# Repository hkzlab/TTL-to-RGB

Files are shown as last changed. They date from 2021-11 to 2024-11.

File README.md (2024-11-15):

# MDA/CGA/EGA/HERCULES TTL-to-ANALOG Converter

## Introduction

This board converts CGA/EGA/MDA/Hercules TTL signals into analog RGB signals that can be fed into a compatible monitor.

Depending on jumper settings, it can automatically detect MDA/Hercules and Hi-res EGA modes (uses vsync polarity detection), can be forced into low-res 64 colors EGA and can perform the "brown-fix" for CGA.

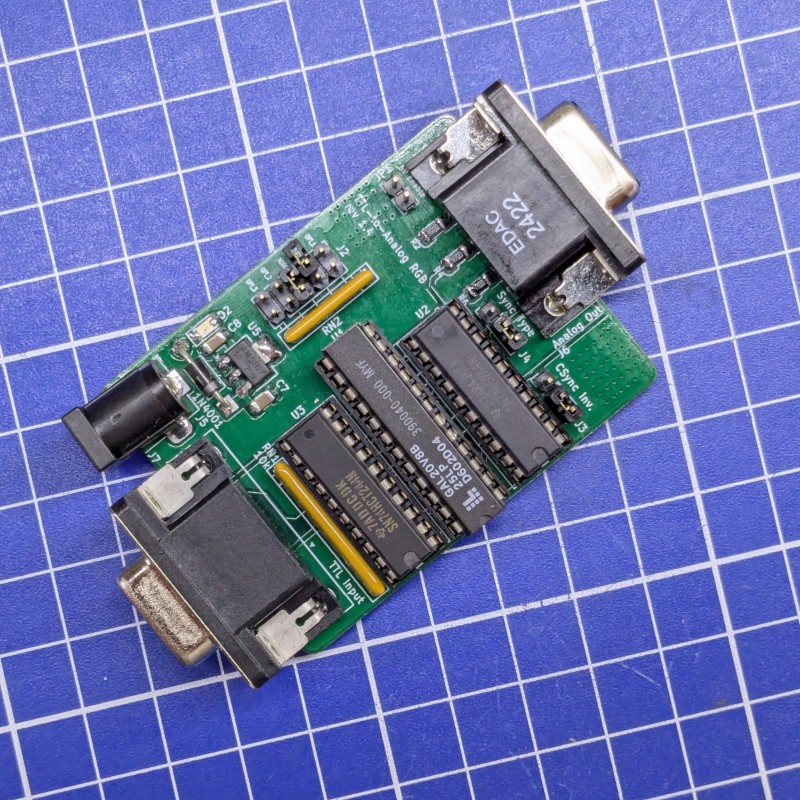
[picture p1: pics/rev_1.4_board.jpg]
Rev. 1.4 Board


The board uses a GAL20V8 PLD to implement the conversions, sync polarity detection, brown-fix, etc.

The PLD is sandwiched between two '244 buffers to protect it from shorts and allow the user to experiment with different logic families to better handle the input. It is recommended to use an 'LS244 as the output buffer, an LS or an HCT is fine for the input.

This board does NOT perform any frequency conversion. You will need a monitor capable of syncing to 15, 18 and 21Khz.

### Pics!

Example of an hi-res EGA game
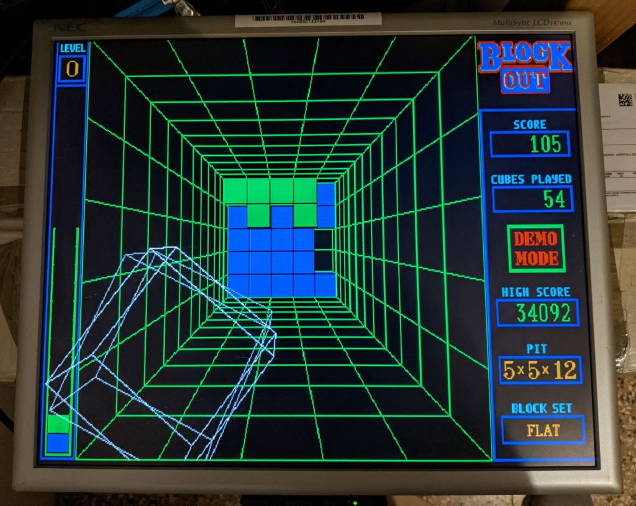
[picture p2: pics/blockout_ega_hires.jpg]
Block Out


Example of a low-res EGA game, with palette choosen between the 64 EGA colors (instead of the 16 CGA colors)
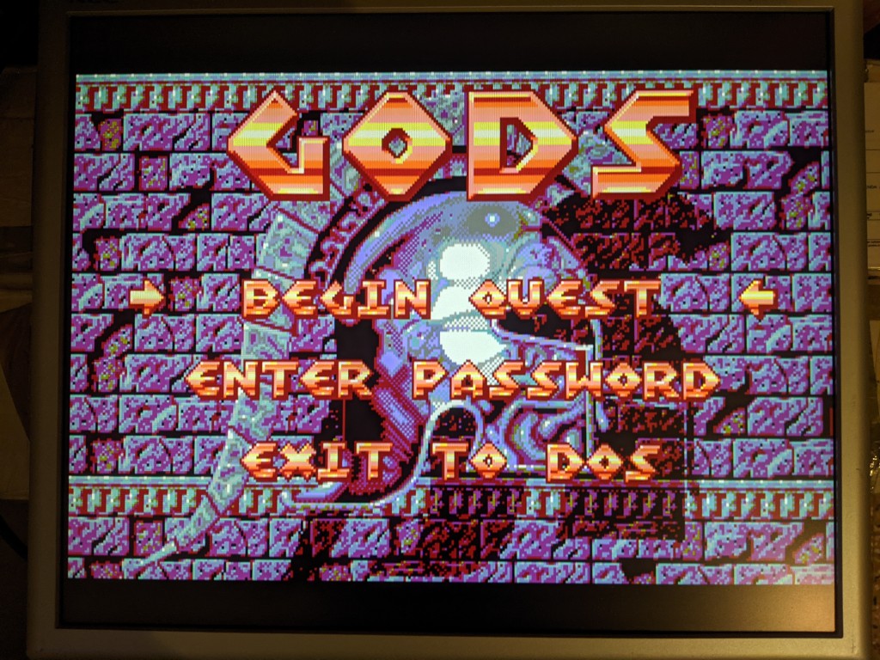
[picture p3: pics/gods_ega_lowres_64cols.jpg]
GODS


### Disclaimer

I take NO responsibility for what happens if you decide to build and use this card. Your computer might crash, catch fire or be destroyed in other nasty ways.
You're encourauged to take what you deem fit from this, and use it in your projects!

### Functionalities

✅ means I tested the functionality and it works, ❌ means I tested the functionality and found issues, ? means that the functionality has yet to be tested.

* [✅] CGA
* [✅] EGA, low-res
* [✅] EGA, low-res, 64 colors
* [✅] EGA, hi-res
* [✅] MDA
* [?] Hercules

## Bill of Materials

**TODO**

## Known Issues

### Rev 1.4

While this revision of the board is basically the same circuit of the previous revisions with some reorganization, the board has not been tested yet!

### Rev 1.2

* Optional power is connected to pin 15 of the HD15 connector, which is not ideal, as the best option would be pin 9. This will be fixed in a later revision (1.4)

### Rev 1.1

* Pin 13 of the GAL is tied to GND, and is currently used to switch between detection modes (CGA/MDA/HERCULES vs CGA/EGA). It can be fixed by a mod
* The board does not provide an option for power output on the HD15 connector. This can be fixed by a mod. Note that the mod will connect power to pin 15, which is not ideal (best would be pin 9), but connecting to the proper location requires desoldering the HD15 and cut more traces.
* With a 12v PSU the regulator gets hot. Use a PSU between 7 and 9v.

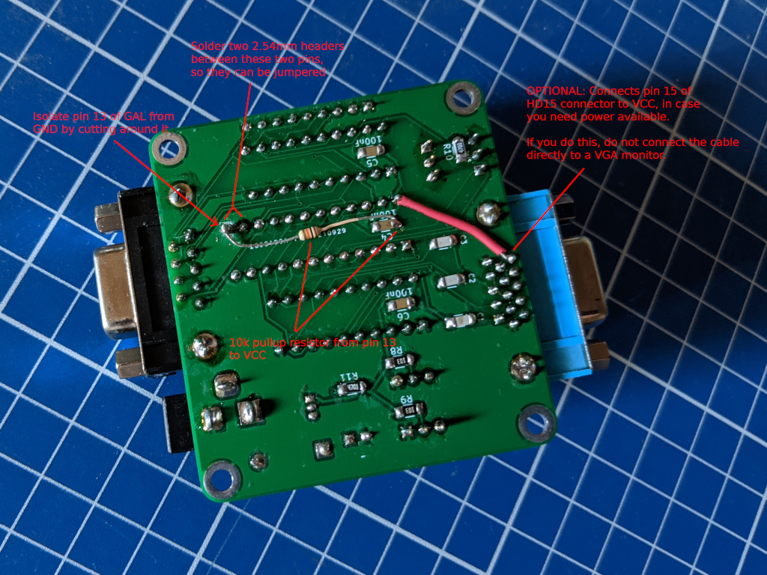
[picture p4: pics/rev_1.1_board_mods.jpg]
Rev. 1.1 Board Mods


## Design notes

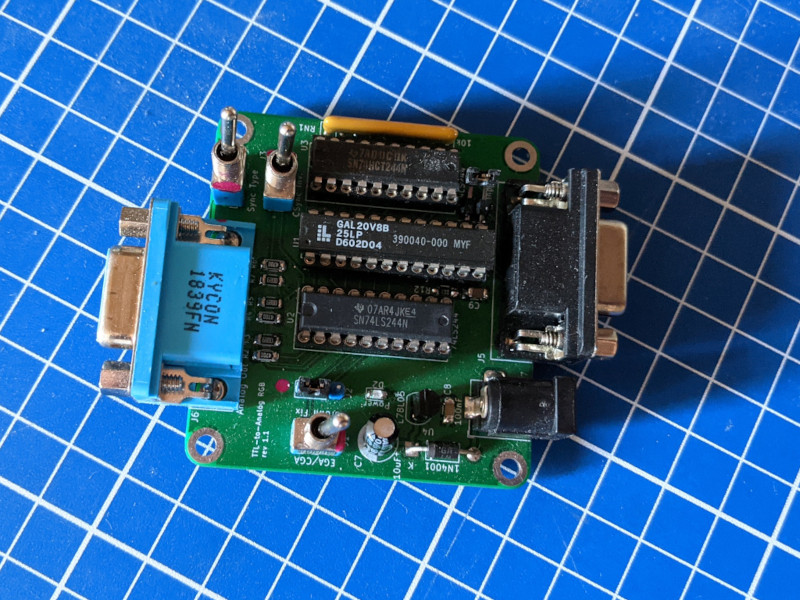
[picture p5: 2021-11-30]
pics/rev_1.1_board.jpg

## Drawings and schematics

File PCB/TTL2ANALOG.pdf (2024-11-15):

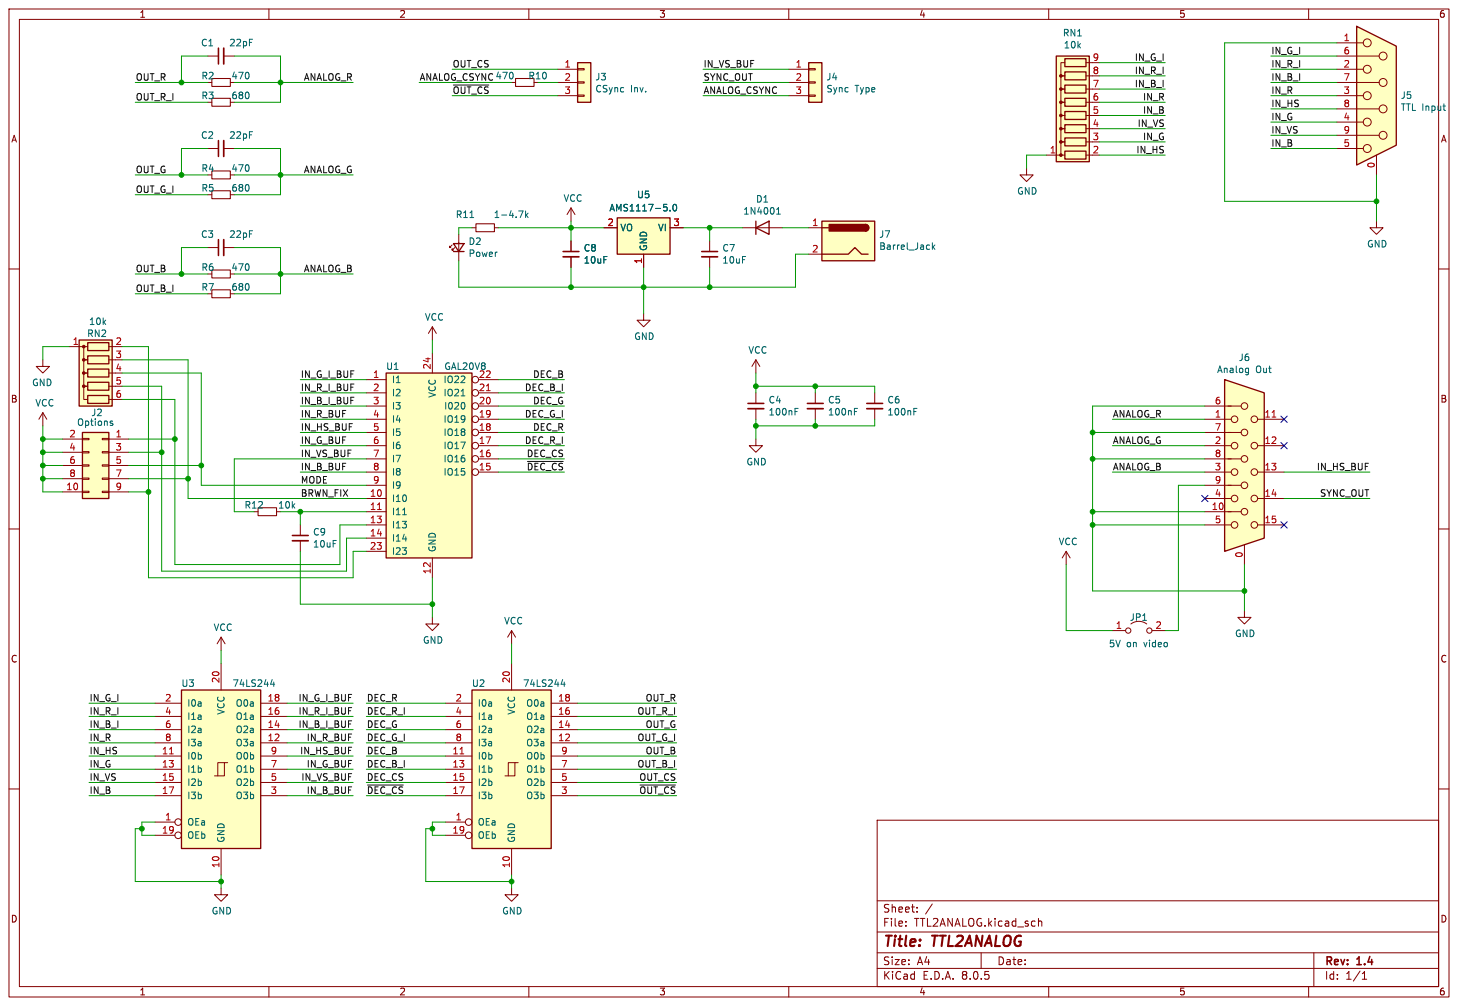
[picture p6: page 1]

1 VO 2 VI 3 U5 AMS1117-5.0 GND GND OEa 1 GND 10

File: TTL2ANALOG.kicad_sch Sheet: / GND 12 VCC 24

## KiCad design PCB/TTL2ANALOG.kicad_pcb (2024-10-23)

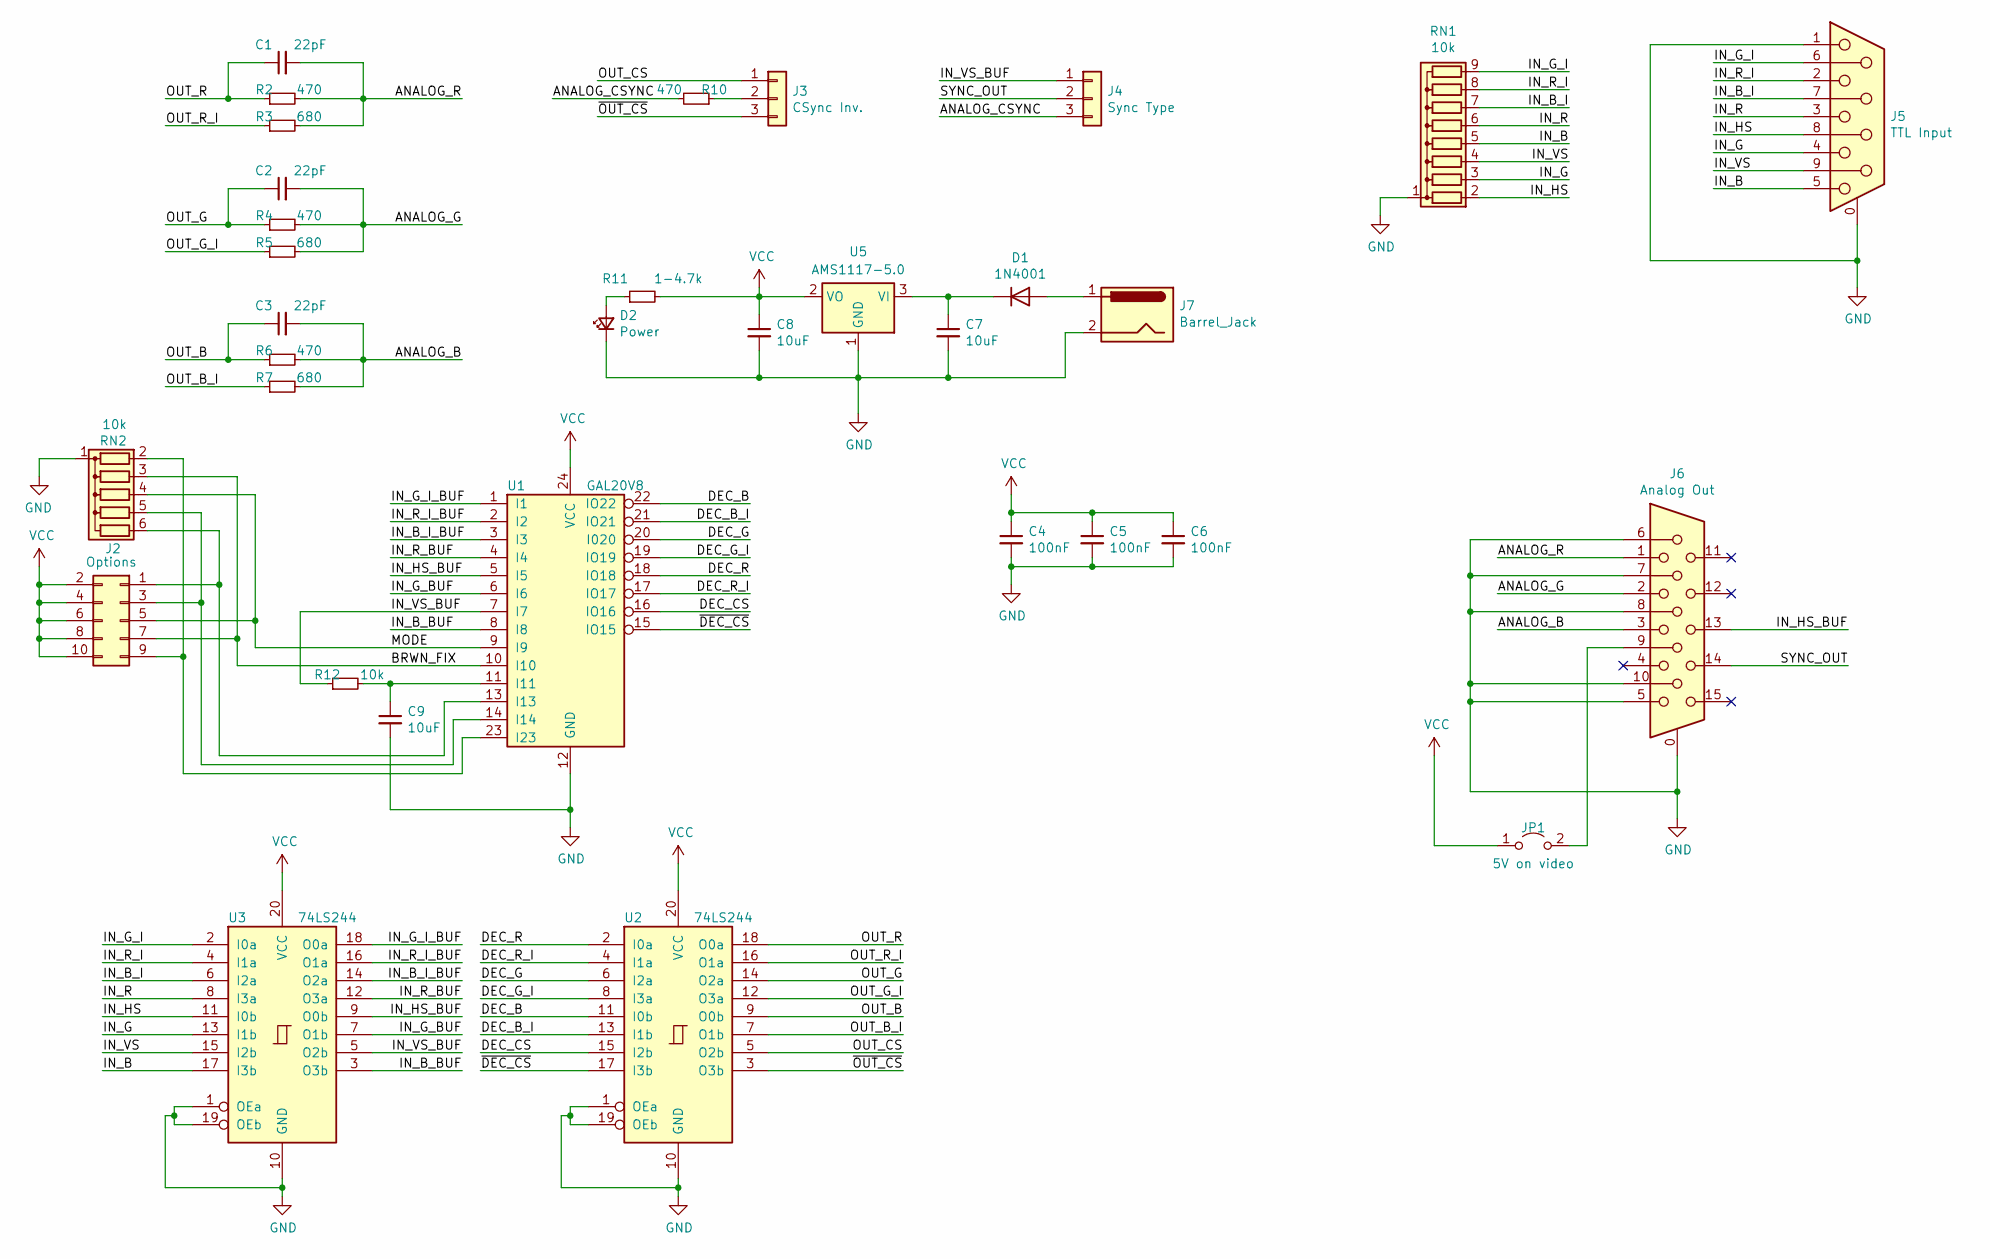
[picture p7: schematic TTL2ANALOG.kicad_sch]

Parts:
C1, C2, C3: 22pF; C_1206_3216Metric_Pad1.33x1.80mm_HandSolder
C4, C5, C6: 100nF; C_1206_3216Metric_Pad1.33x1.80mm_HandSolder
C7, C8, C9: 10uF; C_1206_3216Metric_Pad1.33x1.80mm_HandSolder
D1: 1N4001; D_DO-41_SOD81_P10.16mm_Horizontal
D2: Power; LED_1206_3216Metric_Pad1.42x1.75mm_HandSolder
J2: Options; PinHeader_2x05_P2.54mm_Vertical
J3: CSync Inv.; PinHeader_1x03_P2.54mm_Vertical
J4: Sync Type; PinHeader_1x03_P2.54mm_Vertical
J5: TTL Input; DSUB-9_Female_Horizontal_P2.77x2.84mm_EdgePinOffset4.94mm_H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
J6: Analog Out; DSUB-15-HD_Female_Horizontal_P2.29x1.98mm_EdgePinOffset3.03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
J7: Barrel_Jack; BarrelJack_Horizontal
JP1: 5V on video; PinHeader_1x02_P2.54mm_Vertical
R2, R4, R6, R10: 470; R_1206_3216Metric_Pad1.30x1.75mm_HandSolder
R3, R5, R7: 680; R_1206_3216Metric_Pad1.30x1.75mm_HandSolder
R11: 1-4.7k; R_1206_3216Metric_Pad1.30x1.75mm_HandSolder
R12: 10k; R_1206_3216Metric_Pad1.30x1.75mm_HandSolder
RN1: 10k; R_Array_SIP9
RN2: 10k; R_Array_SIP6
U1: GAL20V8; DIP-24_W7.62mm
U2, U3: 74LS244; DIP-20_W7.62mm_Socket
U5: AMS1117-5.0; SOT-223-3_TabPin2

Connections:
/ANALOG_B: C3.2, J6.3, R6.2, R7.2
/ANALOG_CSYNC: J4.3, R10.2
/ANALOG_G: C2.2, J6.2, R4.2, R5.2
/ANALOG_R: C1.2, J6.1, R2.2, R3.2
/BRWN_FIX: J2.7, RN2.3 (R2), U1.10 (I10)
/DEC_B: U1.22 (IO22), U2.11 (I0b)
/DEC_B_I: U1.21 (IO21), U2.13 (I1b)
/DEC_CS: U1.16 (IO16), U2.15 (I2b)
/DEC_G: U1.20 (I020), U2.6 (I2a)
/DEC_G_I: U1.19 (IO19), U2.8 (I3a)
/DEC_R: U1.18 (IO18), U2.2 (I0a)
/DEC_R_I: U1.17 (IO17), U2.4 (I1a)
/IN_B: J5.5, RN1.5 (R4), U3.17 (I3b)
/IN_B_BUF: U1.8 (I8), U3.3 (O3b)
/IN_B_I: J5.7, RN1.7 (R6), U3.6 (I2a)
/IN_B_I_BUF: U1.3 (I3), U3.14 (O2a)
/IN_G: J5.4, RN1.3 (R2), U3.13 (I1b)
/IN_G_BUF: U1.6 (I6), U3.7 (O1b)
/IN_G_I: J5.6, RN1.9 (R8), U3.2 (I0a)
/IN_G_I_BUF: U1.1 (I1), U3.18 (O0a)
/IN_HS: J5.8, RN1.2 (R1), U3.11 (I0b)
/IN_HS_BUF: J6.13, U1.5 (I5), U3.9 (O0b)
/IN_R: J5.3, RN1.6 (R5), U3.8 (I3a)
/IN_R_BUF: U1.4 (I4), U3.12 (O3a)
/IN_R_I: J5.2, RN1.8 (R7), U3.4 (I1a)
/IN_R_I_BUF: U1.2 (I2), U3.16 (O1a)
/IN_VS: J5.9, RN1.4 (R3), U3.15 (I2b)
/IN_VS_BUF: J4.1, R12.1, U1.7 (I7), U3.5 (O2b)
/MODE: J2.5, RN2.4 (R3), U1.9 (I9)
/OUT_B: C3.1, R6.1, U2.9 (O0b)
/OUT_B_I: R7.1, U2.7 (O1b)
/OUT_CS: J3.1, U2.5 (O2b)
/OUT_G: C2.1, R4.1, U2.14 (O2a)
/OUT_G_I: R5.1, U2.12 (O3a)
/OUT_R: C1.1, R2.1, U2.18 (O0a)
/OUT_R_I: R3.1, U2.16 (O1a)
/SYNC_OUT: J4.2, J6.14
/~DEC_CS: U1.15 (IO15), U2.17 (I3b)
/~OUT_CS: J3.3, U2.3 (O3b)
GND: C4.2, C5.2, C6.2, C7.2, C8.2, C9.2, D2.1 (K), J5.0 (PAD), J5.1, J6.0, J6.5, J6.6, J6.7, J6.8, J6.10, J7.2, RN1.1 (common), RN2.1 (common), U1.12 (GND), U2.1 (OEa), U2.10 (GND), U2.19 (OEb), U3.1 (OEa), U3.10 (GND), U3.19 (OEb), U5.1 (GND)
unnamed: D1.2 (A), J7.1
unnamed: C7.1, D1.1 (K), U5.3 (VI)
unnamed: D2.2 (A), R11.1
unnamed: J2.1, RN2.6 (R5), U1.13 (I13)
unnamed: J2.3, RN2.5 (R4), U1.14 (I14)
unnamed: J2.9, RN2.2 (R1), U1.23 (I23)
unnamed: J3.2, R10.1
unnamed: J6.9, JP1.2 (B)
unnamed: C9.1, R12.2, U1.11 (I11)
VCC: C4.1, C5.1, C6.1, C8.1, J2.2, J2.4, J2.6, J2.8, J2.10, JP1.1 (A), R11.2, U1.24 (VCC), U2.20 (VCC), U3.20 (VCC), U5.2 (VO)

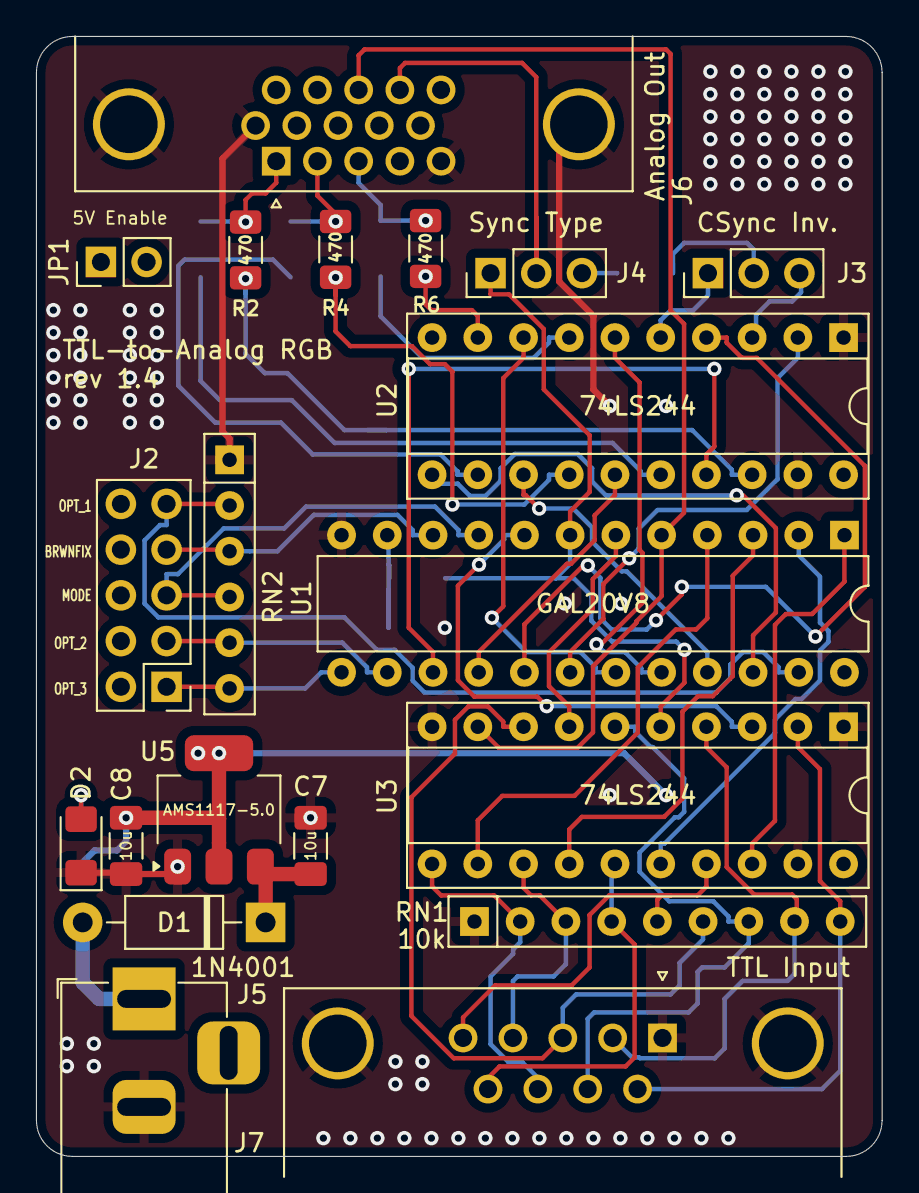
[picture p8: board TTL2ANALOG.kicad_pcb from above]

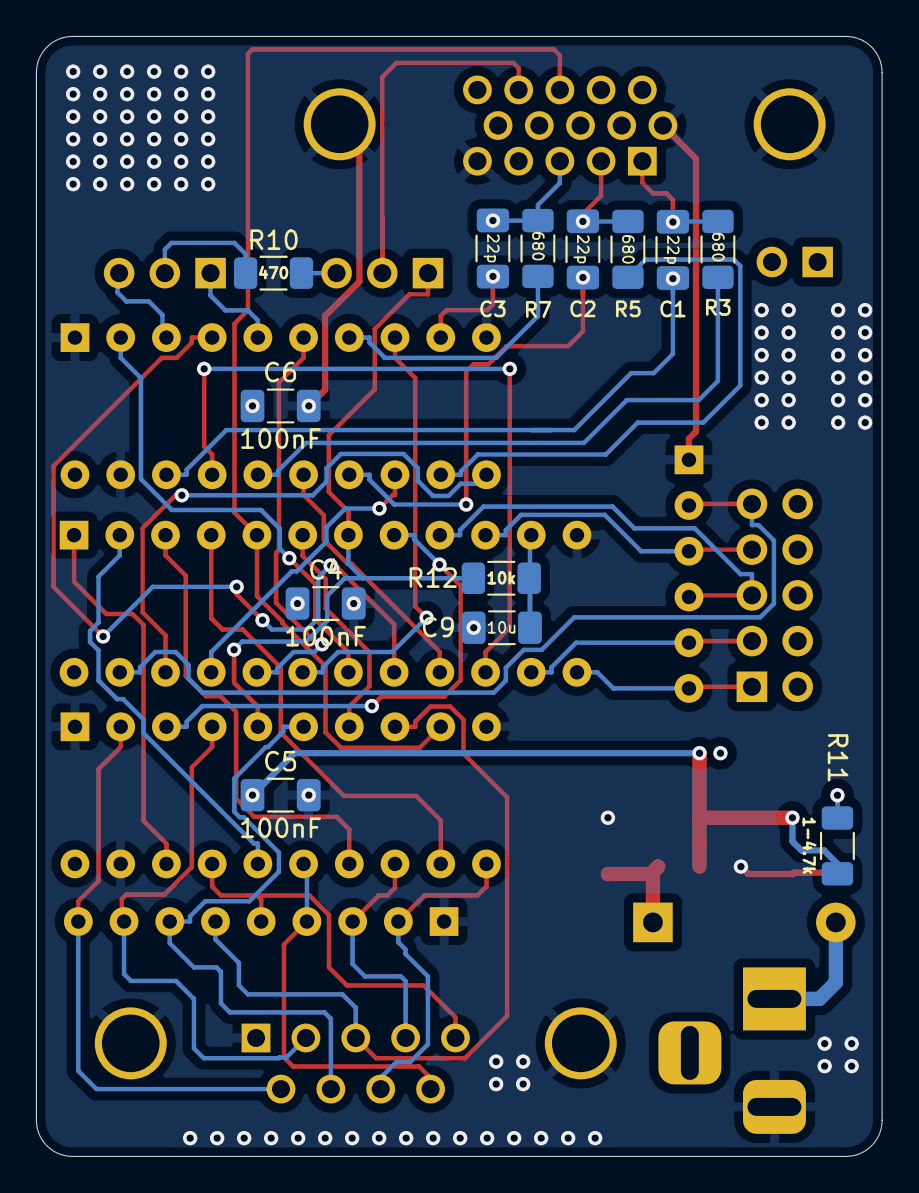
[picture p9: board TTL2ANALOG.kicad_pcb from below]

Board: 4 copper layers, 47.0 x 62.2 mm, 33 parts (13 on the bottom side), 50 nets.

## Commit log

2021-09-07 Begin adding new components to the board
    [TTL2ANALOG.sch]
2021-09-07 Begin drawing PCB
    [TTL2ANALOG.kicad_pcb, TTL2ANALOG.sch]
2021-09-07 Continue drawing PCB
    [TTL2ANALOG.kicad_pcb, TTL2ANALOG.sch]
2021-09-07 Draw PCB
    [TTL2ANALOG.kicad_pcb, TTL2ANALOG.sch]
2021-09-07 Complete main circuit
    [TTL2ANALOG.kicad_pcb, TTL2ANALOG.sch]
2021-09-07 Notes to equations
    [TTL2ANALOG.sch]
2021-09-07 Add silkscreen
    [TTL2ANALOG.kicad_pcb]
2021-09-07 Add gerbers
2021-09-07 Save prefs
    [TTL2ANALOG.kicad_pcb]
2021-09-08 Add pulldown resistor on inputs
    [TTL2ANALOG.kicad_pcb, TTL2ANALOG.sch]
2021-09-09 Change PCB, use GAL20V8
    [TTL2ANALOG.kicad_pcb, TTL2ANALOG.sch]
2021-10-20 Update PCB to add 10k to VCC res to VGA out
    [TTL2ANALOG.kicad_pcb, TTL2ANALOG.sch]
2021-10-20 Use a TO220 7805 in new revision
    [TTL2ANALOG.kicad_pcb, TTL2ANALOG.sch]
2021-10-20 slightly change silkscreen
    [TTL2ANALOG.kicad_pcb]
2021-10-20 Add gerbers for rev 1.2, remove deprecated and untested 1.1
2021-10-21 Begin drawing the 1.3 revision
    [TTL2ANALOG.sch]
2021-10-21 Changed the default state of the option plug
    [TTL2ANALOG.sch]
2021-10-28 Replace a bridge with an header
    [TTL2ANALOG.sch]
2023-10-23 Import to KiCad 7 and update the README with known issues
    [TTL2ANALOG.kicad_pcb, TTL2ANALOG.kicad_sch, TTL2ANALOG.sch]
2024-10-19 Redraw version 1.4
    [TTL2ANALOG.kicad_pcb, TTL2ANALOG.kicad_sch]
2024-10-23 Create gerbers for rev 1.4
    [TTL2ANALOG.kicad_pcb]
2024-11-15 Update README, add schematic, and 1.4 picture
